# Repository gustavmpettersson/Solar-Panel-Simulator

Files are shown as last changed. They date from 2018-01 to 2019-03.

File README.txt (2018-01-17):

Solar Panel Simulator (SPS) for CubeSat testing

If you use any of this work, we ask that you cite the following individuals and provide a 
link to this repository:
Gustav M. Pettersson
Malte Gruber
Theodor-Adrian Stana
Sven Grahn
Christer Fuglesang
<https://github.com/gustavmpettersson/Solar-Panel-Simulator/>

This project is distributed in the hope that it will be useful, but WITHOUT ANY WARRANTY; 
without even the implied warranty of MERCHANTABILITY or FITNESS FOR A PARTICULAR PURPOSE. 
This should be considered EXPERIMENTAL RESEARCH technology and appropriate care should be 
taken. We will NOT be responsible for ANY related DAMAGES or ISSUES.

This work is Open Source Software and Hardware. See the two included <LICENSE.txt> files 
for details. The software is Copyright 2018 Gustav Pettersson, and released under the GNU 
General Public License. The hardware is Copyright 2018 Gustav Pettersson and Malte Gruber, 
and released under the CERN Open Hardware Licence.

In the root of this repository is a preprint of an article on the SPS submitted to Acta
Astronautica. It contains a lot of (hopefully) useful information on the system.

This system was designed by people working on the MIST and SEAM projects at the KTH Royal 
Institute of Technology.

We invite discussion, collaboration and help with implementing the system. Please contact 
us at <gupet@kth.se> or <gustavpettersson@live.com>.

HERE TO USE THE SPS? START BY READING <Introduction to the SPS>.

HERE TO BUILD THE SPS? HEAD INTO THE HARDWARE FOLDER FOR NECCESSARY FILES. THEN GO TO THE
<Building and Calibrating> FOLDER AND READ <Building Testing and Calibrating the SPS>.

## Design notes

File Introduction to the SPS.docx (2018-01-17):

# Introduction to the SPS

Gustav Pettersson January 2018

# Why the SPS?

Solar panels are used on CubeSats to generate power for the satellite to function. It is vital that the power system on the satellite works as intended to generate the most amount of power possible, and that it has been tested thoroughly. The Solar Panel Simulator (SPS) is used for this purpose. It is a piece of electronics which is designed to act precisely like a solar panel, and in which the exact characteristics of this solar panel can be controlled. It is key to recognise that solar panels do not act like a typical power supply which generates a fixed voltage (and has a maximum amount of current which may be drawn). Instead, a solar panel needs to be actively controlled. The panel presents a characteristic curve of current vs voltage; for each unique voltage applied on the panel by the satellite, a certain current will be delivered. This curve is called the IV curve and is central to understanding the workings and purpose of the SPS. A typical IV curve looks like the solid line below:

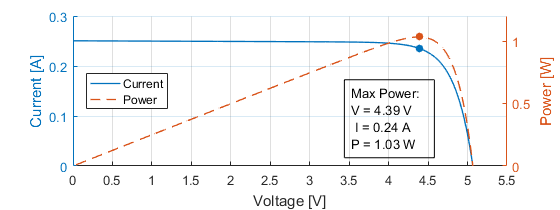
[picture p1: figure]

At a zero voltage, the solar panel produces a certain current (the short-circuit current). As the applied voltage increases, there will be an exponential fall in the produced current, eventually going to zero (the open-circuit voltage). Power (which is what we want!) is the product of voltage and current. Therefore, there is a balance where the voltage is “just right” and the maximum amount of power is produced! This is called the Maximum Power Point (MPP). The power is given in the same plot as the broken line, and the MPP is marked. The satellite power system will try to “chase” this voltage to generate the maximum amount of power. This is called a MPP Tracker (MPPT) and it is implemented in the Solar Array Interface (SAI) of the power system.

# What is the SPS?

The SPS is a device in which an arbitrary IV curve can be programmed to simulate any solar panel on a satellite. It works by measuring the voltage applied by the SAI and then delivering the current programmed into the Lookup Table (LUT) which gives the correct curve. It updates 1000 times per second to ensure the correct current is always given! It looks like this:

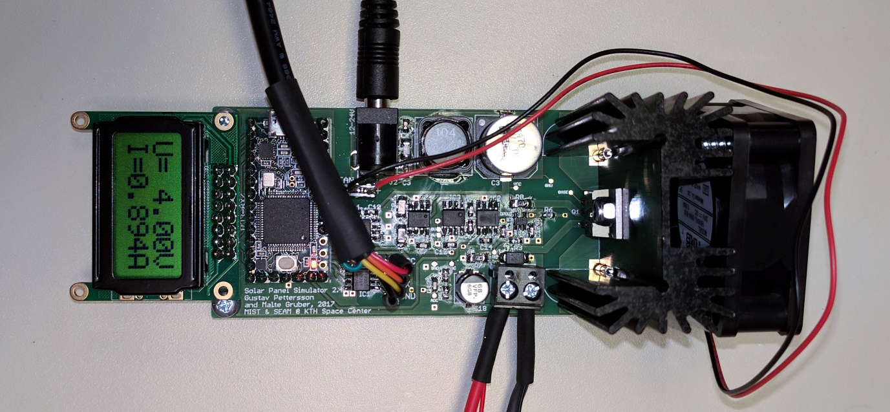
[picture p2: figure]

5 The fan runs directly from the power supply!

6 The fan runs directly from the power supply!

2

4

3

1

There are some key things to point out:

1. The power input. Use a DC power source of 12-24V which is of high quality and isolated from the mains power supply.
2. The power output. This side gets connected to the satellite power system as an input. Please take care that the SPS output is disabled and that the polarity is correct! It is highly recommended to use a connector on this wire (like the one listed in the parts list).
3. The UART connection. This is how the SPS is controlled by the computer. You need to have a UART adapter which provides 3.3-5V connected here, please care for the polarity.
4. The display. This shows what the current output voltage and current is for this SPS. It is very useful to understand how the satellite power system is working!
5. The fan. If you do not use a fan the output is limited to up to 8V 1.1A and a 12V input must be used. If you want to use up to 21V 1.1A, add a 24V fan and use a 24V power supply. If you want to use up to 8V 2.1A use a 12V fan and a 12V power supply. The fan runs directly from the power supply!
6. The Teensy microcontroller. This guy is the brains behind all of it. To program the Teensy use the USB port on it. Never connect power to the SPS and the Teensy USB port at the same time. You may kill your SPS or even your PC!

# How to use the SPS?

Now that we are acquainted, it is time to use the SPS! You will need to know some things:

1. How many inputs will you run?
2. For each input:
  a. What is the maximum voltage and current of the solar panel(s) normally connected?
  b. How will I connect the SPS: Into the harness in place of a panel, or into the power system directly?
3. Do you have an SPS on hand for each input with the correct current and voltage rating?
4. Are you ready to take full responsibility for what happens? The SPS works great for us, but we guarantee nothing. Know what you’re doing, flight hardware is expensive!

If you know these things, go to the instructions for manual control of SPSs in the folder “SPS Manual Control GUI”. Have fun!

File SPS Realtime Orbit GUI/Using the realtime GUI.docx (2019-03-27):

# Using the real-time GUI

Gustav Pettersson January 2018

# Ensure:

You have successfully connected and used all the SPSs on their respective inputs using the manual control GUI. It is imperative that this is done so that everything is connected correctly! If you have not, go to the “SPS Manual Control GUI” folder and follow those instructions.

This guide is only true for the MIST satellite because the simulation data sample in this folder was made for the MIST satellite. This guide is still a useful instruction to understand the purpose and use of the SPS real-time system. We are happy to assist in integrating your simulations for your satellite, just send me an email. Using MIST data on your satellite may destroy it!

# Software setup:

Since you have successfully used the manual GUI and ensured everything is correct, copy exactly the setup from “runManual_SPS_GUI” into “runRealtime_SPS_GUI”. I.e. something like the following:

SPS_HW_IDS = [7 5 6];

SPS_TYPES = {'NO' 'HC' 'HV'};

SPS_LABELS = {'MPPT 1' 'MPPT 2' 'MPPT 3'};

After this, put the desired file to replay in the load statement. E.g. for the sample included:

load('simulationData_MIST_sample.mat');

By default, the software will replay one orbit and then stop. If you wish for it to instead loop back and start from the beginning, add the optional input “true” when starting the GUI:

Stop after one orbit: Realtime_SPS_GUI(SPSs,simulationData);

Loop back to beginning: Realtime_SPS_GUI(SPSs,simulationData,true);

# Hardware setup:

When you have successfully used the manual GUI, do not disconnect the SPSs (to ensure they are not accidentally mixed up) but just close the GUI windows.

# Running:

Run the script. A GUI looking like this should open:

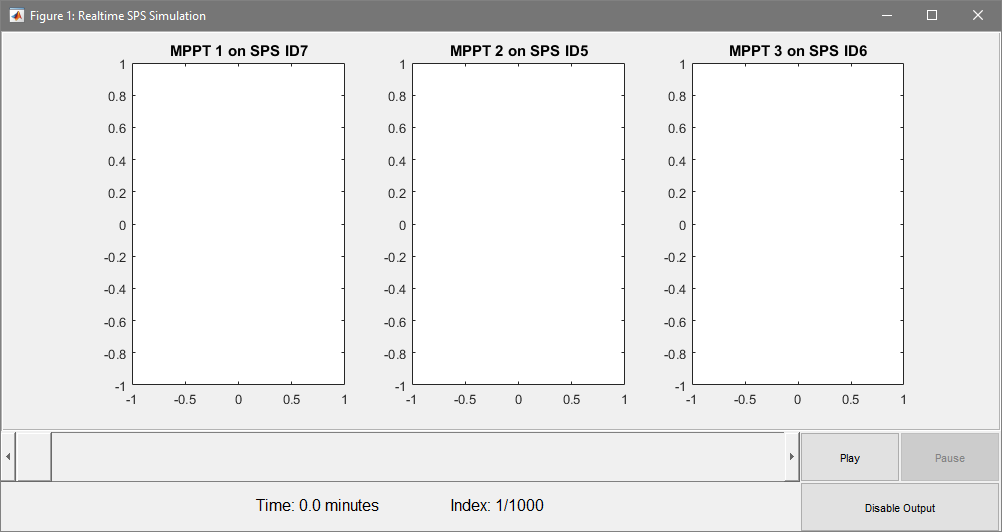
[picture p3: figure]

The top part of this GUI shows one plot window for each SPS. What is shown here is always the curve which is programmed into that SPS. If it is blank like here the SPS is disabled. Along the bottom are the controls. There is a timeline which you may move to a desired starting point; the selected time and index in the simulation are shown. The bottom right holds the controls. Pressing “Play” will start the real-time simulation. In the sample simulation, the satellite comes out of eclipse at around 11 minutes, so this is a good starting point. Press “Play” and you should soon see IV curves appearing. At any time, pressing “Pause” will halt the simulation but keep the current output active. It should look like this:

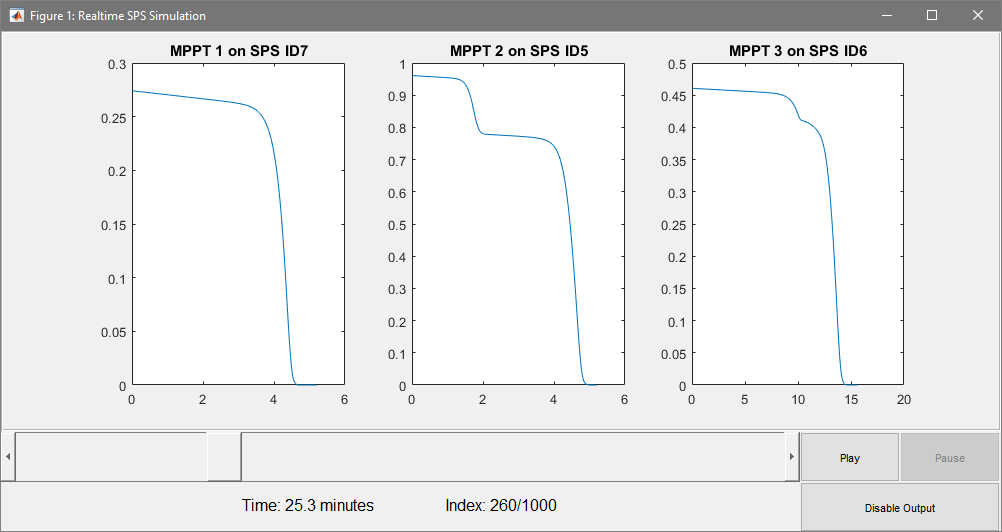
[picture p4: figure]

On the other hand, pressing “Disable Output” will disable the output on the SPSs (and halt the simulation). Now press play and enjoy!

# Shutting down

When finished the program will disable the outputs. If you want to finish early, press “Disable Output”. Read the display on the SPS, it should read (almost) 0A of current. Disconnect it from the satellite power system before unplugging the power to the SPS. Close the Matlab window (If you have unplugged the SPS power, you will get an error message in Matlab, this is expected).

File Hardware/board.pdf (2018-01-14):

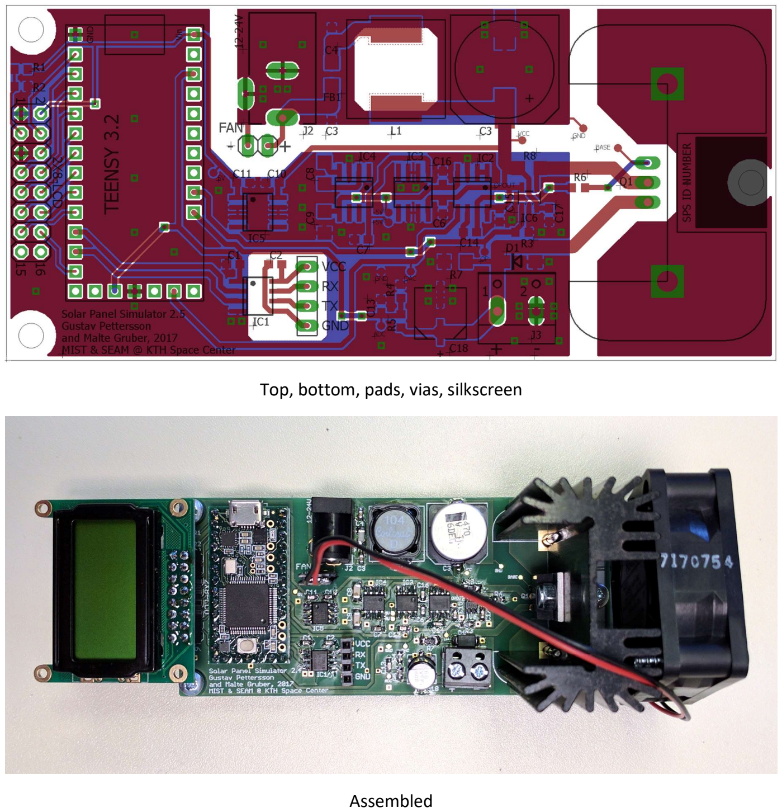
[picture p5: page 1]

Top, bottom, pads, vias, silkscreen

Assembled

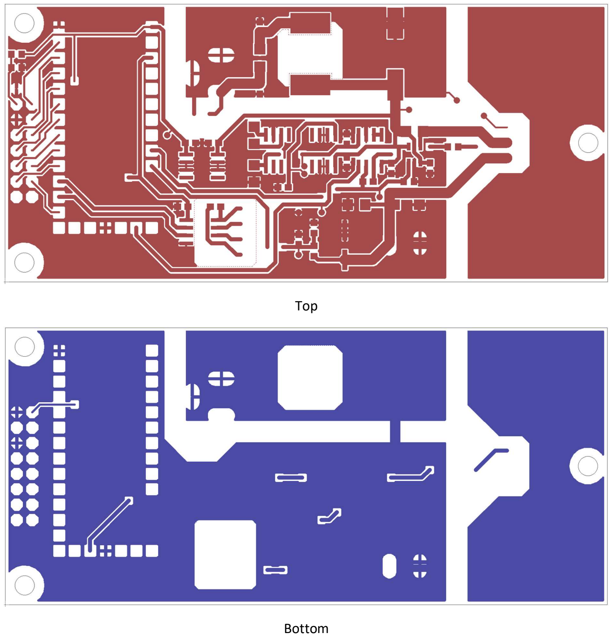
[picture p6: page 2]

Top

Bottom

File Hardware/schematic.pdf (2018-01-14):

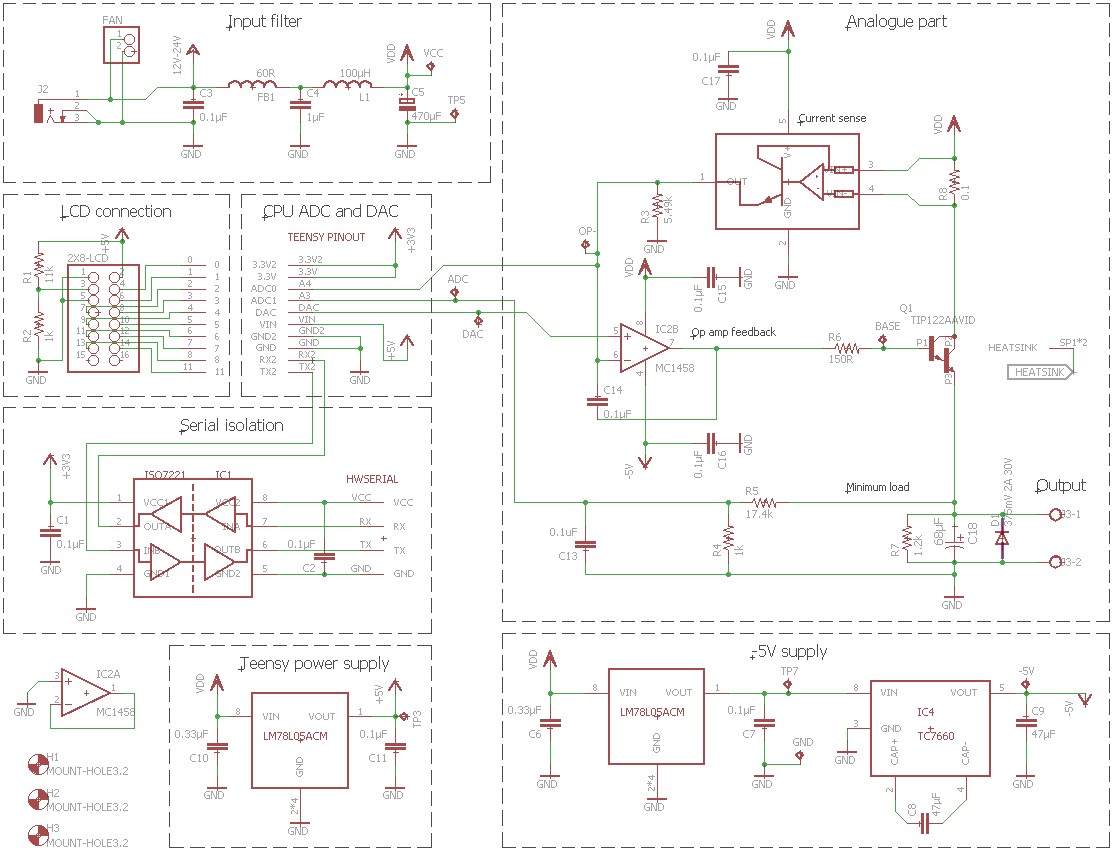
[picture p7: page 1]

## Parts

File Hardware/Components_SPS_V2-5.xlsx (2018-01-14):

Type | Package | Farnell code | Pieces | Note | Components
0.1µF MLCC | 0603 | 2525112 (http://se.farnell.com/tdk/c1608x7r1h104m080aa/kond-mlcc-x7r-0-1-f-50v-0603/dp/2525112) | 11 |  | C1,2,3,7,11,13,14,15,16,17 | Don't mount C12
0.33µF MLCC | 0603 | 2346907 (http://se.farnell.com/tdk/c1608x7r1h334k080ac/cap-mlcc-x7r-330nf-50v-0603/dp/2346907) | 2 |  | C6,10
1µF MLCC | 0603 | 2346909 (http://se.farnell.com/tdk/c1608x7r1v105k080ac/cap-mlcc-x7r-1uf-35v-0603/dp/2346909) | 1 |  | C4
47µF MLCC | 1206 | 2426965 (http://se.farnell.com/murata/grm31cr61a476ke15l/cap-mlcc-x5r-47uf-10v-1206/dp/2426965) | 2 |  | C8,9
68µF Electrolytic | 8mm | 1539500 (http://se.farnell.com/panasonic-electronic-components/eeefpv680xap/cap-alu-elec-68uf-35v-smd/dp/1539500) | 1 |  | C18
470µF Electrolytic | 12.5mm | 2079237 (http://se.farnell.com/panasonic-electronic-components/eeetkv471uaq/cap-alu-elec-470uf-35v-smd/dp/2079237) | 1 |  | C5
0.1R 1% | 1206 | 1107359 (http://se.farnell.com/vishay/wsl1206r1000fea/motst-metallfilm-r1-1-250mw-1206/dp/1107359) | 1 |  | R8
150R 1% | 0603 | 2447255 (http://se.farnell.com/multicomp/mcwr06x1500ftl/res-thick-film-150-ohm-1-0-1w/dp/2447255) | 1 |  | R6
1k 1% | 0603 | 2447272 (http://se.farnell.com/multicomp/mcwr06x1001ftl/motst-tjockfilm-1k-1-0-1w-0603/dp/2447272) | 2 |  | R2,4
1.2k 0.5W | 1206 | 2331866 (http://se.farnell.com/te-connectivity/crgh1206j1k2/motst-tjockfilm-1k2-5-0-5w-1206/dp/2331866) | 1 |  | R7
5.49k 1% | 0603 | 2670841 (http://se.farnell.com/walsin/wr06x5491ftl/motst-tjockfilm-5k49-1-0-1w-0603/dp/2670841) | 1 |  | R3
11k 1% | 0603 | 2447237 (http://se.farnell.com/multicomp/mcwr06x1102ftl/res-thick-film-11kohm-1-0-1w/dp/2447237) | 1 |  | R1
17.4k 1% | 0603 | 2670666 (http://se.farnell.com/walsin/wr06x1742ftl/motst-tjockfilm-17k4-1-0-1w-0603/dp/2670666) | 1 |  | R5
100µH MSS1210-104 | 1210 | 2288307 (http://se.farnell.com/coilcraft/mss1210-104ked/inductor-pwr-100uh-3-4a-10-3-6mhz/dp/2288307) | 1 |  | L1
2A 375mV 30V Schottky | DO-214AC | 1467552 (http://se.farnell.com/stmicroelectronics/stps2l30a/diode-schottky-2a-30v-smd-sma/dp/1467552) | 1 |  | D1
60R Ferrite bead | 1206 | 1651732 (http://se.farnell.com/taiyo-yuden/fbmj3216hm600-t/ferrite-bead-0-01ohm-4a-1206/dp/1651732) | 1 |  | FB1
LM78L05ACM | SO-8 | 2382979 (http://se.farnell.com/texas-instruments/lm78l05aim-nopb/linear-fixed-5v-0-1a-soic-8/dp/2382979) | 2 |  | IC3,5
INA139 | SOT-23 | 1470398 (http://se.farnell.com/texas-instruments/ina139na-250/current-shunt-monitor-40v-5sot23/dp/1470398) | 1 |  | IC6
TC7660 | SO-8 | 1852313 (http://se.farnell.com/microchip/tc7660eoa/ic-charge-pump-dc-dc-conv-8soic/dp/1852313) | 1 |  | IC4
MC1458 | SO-8 | 9589821 (http://se.farnell.com/texas-instruments/mc1458d/op-amp-gen-purpose-dual-smd-1458/dp/9589821) | 1 |  | IC2
ISO7221A | SO-8 | 2764741 (http://se.farnell.com/texas-instruments/iso7221adr/digital-isolator-2-kan-1-5mbps/dp/2764741) | 1 |  | IC1
TIP122 | TO220 | 9557881 (http://se.farnell.com/on-semiconductor/tip122g/darlington-transistor-to-220/dp/9557881) | 1 |  | Q1
8x2 LCD |  | 2674124 (http://se.farnell.com/fordata/fc0802c00-rnnybh-16le/display-alfanumerisk-8x2-inget/dp/2674124) | 1
20p 0.1" male |  | 1593423 (http://se.farnell.com/multicomp/mc34739/connector-header-tht-2-54mm-20way/dp/1593423) | 2
4p 0.1" female |  | 1593460 (http://se.farnell.com/multicomp/2212s-04sg-85/socket-pcb-1-row-4way/dp/1593460) | 1
8x2p 0.1" male |  | 1593445 (http://se.farnell.com/multicomp/2213s-16g/header-2-row-vert-16way/dp/1593445) | 1
5mm terminal block |  | 1716993 (http://se.farnell.com/camdenboss/ctb1202-2bk/terminal-block-wire-to-brd-2pos/dp/1716993) | 1
5.5/2.1mm DC Jack (10 pack) |  | 224959 (http://se.farnell.com/cliff-electronic-components/dc10a/socket-pcb-dc-power-2-1mm-pk10/dp/224959) | 1
AAVID Heatsink |  | 1213474 (http://se.farnell.com/aavid-thermalloy/6399bg/heat-sink-to-220-218-3-3-c-w/dp/1213474) | 1
12V Fan | 40mm | 1012746 (http://se.farnell.com/nmb-technologies/1606kl-04w-b50-l00/fan-40mm-12vdc/dp/1012746) | 1 | for HC
24V Fan | 40mm | 1012748 (http://se.farnell.com/nmb-technologies/1606kl-05w-b50-l00/fan-40mm-24vdc/dp/1012748) | 1 | for HV
12V Power supply |  | 2708288 (http://se.farnell.com/xp-power/vet30us120c2-ja/adapter-ac-dc-12v-2-5a/dp/2708288) | 1 | for HC
24V Power supply |  | 2708291 (http://se.farnell.com/xp-power/vet30us240c2-ja/adapter-ac-dc-24v-1-25a/dp/2708291) | 1 | for HV
Mains cable |  | 1283799 (http://se.farnell.com/pro-elec/sh10167r/power-cord-euro-to-fig-8-2m/dp/1283799) | 1
USB cable |  | 2464950 (http://se.farnell.com/roline/11-02-8760/kabel-usb-2-0-a-micro-b-kont-1m/dp/2464950) | 1
Teensy 3.2 board |  | Mouser/PJRC | 1
M3 6mm (100 pack) |  | 1419986 (http://se.farnell.com/duratool/m36-prstmcz100/screw-steel-bzp-6mm-m3-pk100/dp/1419986) | 4
M3 nut (100 pack) |  | 1420431 (http://se.farnell.com/duratool/m3-n5st-z100/nut-locking-steel-bzp-m3-pk100/dp/1420431) | 1
M3 20mm self tap (100 pack) |  | 2474974 (http://se.farnell.com/tr-fastenings/3-020krst30tc1d/skruv-pozi-g-ngbildande-m3-x-20mm/dp/2474974) | 2
M3 8mm standoff |  | 1466741 (http://se.farnell.com/ettinger/05-03-083/spacer-m3x8-ni/dp/1466741) | 3

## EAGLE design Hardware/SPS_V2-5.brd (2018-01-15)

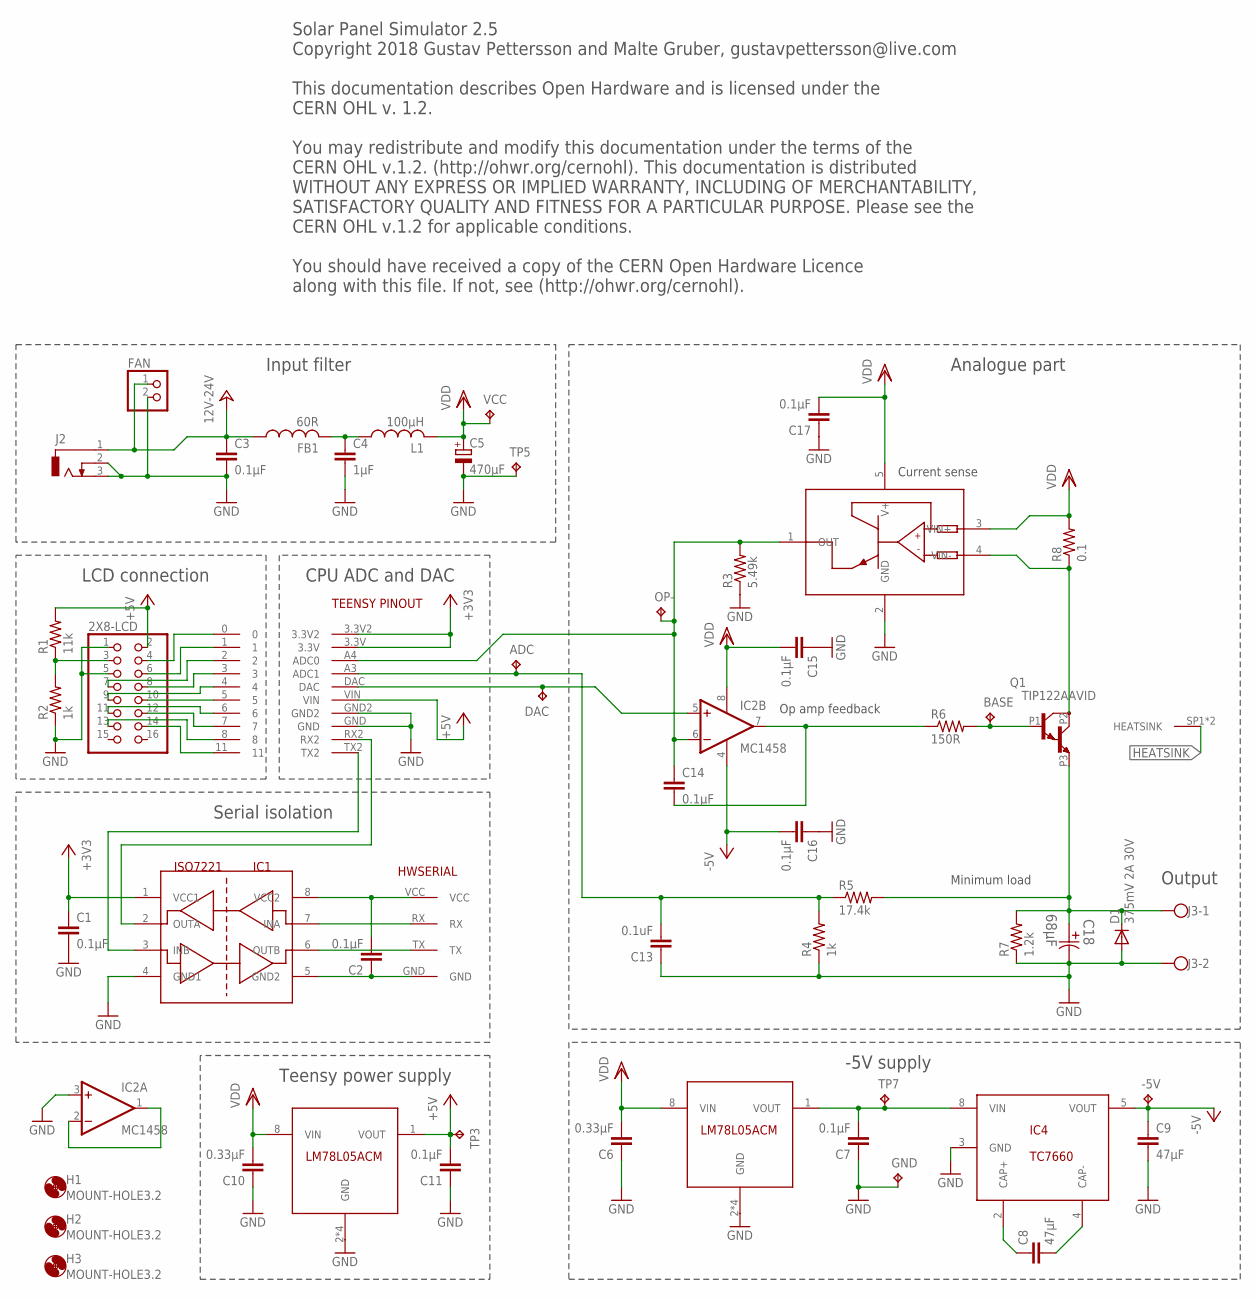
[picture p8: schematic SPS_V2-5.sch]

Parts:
2X8-LCD: PINHD-2X8; 2X08
-5V: TPTP10R; TP10R
ADC: TPTP10R; TP10R
BASE: TPTP10R; TP10R
C1, C2, C3, C7, C11, C14, C15, C16, C17: 0.1µF; C0603
C4: 1µF; C0603
C5: 470µF; 12.5MMSMD
C6, C10: 0.33µF; C0603
C8, C9: 47µF; C1206
C13: 0.1uF; C0603
C18: 68µF; CAPAE660X800N
D1: 375mV 2A 30V; DO214AC
DAC: TPTP10R; TP10R
DB1: TEENSY3.2
FAN: PINHD-1X2; 1X02
FB1: 60R; R1206
GND: TPTP10R; TP10R
H1, H2, H3: MOUNT-HOLE3.2; 3,2
IC1: ISO7221; SO8
IC2: MC1458; SO08
IC3, IC5: LM78L05ACM; SO8
IC4: TC7660; SO8
IC6: INA139; SOT23-5L
J1: HWSERIAL
J2: DCJ0303
J3: W237-102
L1: 100µH; 1210INDUCTOR
OP-: TPTP10R; TP10R
Q1: TIP122AAVID; OP-220-AAVID
R1: 11k; R0603
R2, R4: 1k; R0603
R3: 5.49k; R0603
R5: 17.4k; R0603
R6: 150R; R0603
R7: 1.2k; R1206
R8: 0.1; R1206
TP3, TP5, TP7: TPTP10R; TP10R
VCC: TPTP10R; TP10R

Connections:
+3V3: C1.1, DB1.3.3V, DB1.3.3V2, IC1.1 (VCC1)
+5V: 2X8-LCD.2, C11.2, DB1.VIN, IC5.1 (VOUT), R1.2, TP3.TP
+24V: C3.1, FAN.1, FB1.1, J2.1
-5V: -5V.TP, C9.1, C16.2, IC2.4 (V-), IC4.5 (VOUT)
GND: 2X8-LCD.1, 2X8-LCD.5, C1.2, C3.2, C4.2, C5.P$1 (-), C6.1, C7.1, C9.2, C10.1, C11.1, C13.1, C15.1, C16.1, C17.1, C18.2, D1.A, DB1.GND, DB1.GND2, FAN.2, GND.TP, IC1.4 (GND1), IC2.3 (+IN), IC3.2 (GND), IC3.3 (GND), IC3.6 (GND), IC3.7 (GND), IC4.3 (GND), IC5.2 (GND), IC5.3 (GND), IC5.6 (GND), IC5.7 (GND), IC6.2 (GND), J2.2, J2.3, J3.2, R2.1, R3.1, R4.1, R7.1, TP5.TP
HEATSINK: Q1.SP1 (HEATSINK), Q1.SP2 (HEATSINK)
unnamed: C14.2, IC2.7 (OUT), R6.1
unnamed: BASE.TP, Q1.P1 (B), R6.2
unnamed: C4.1, FB1.2, L1.P$1 (1)
unnamed: C14.1, DB1.A4 (ADC0), IC2.6 (-IN), IC6.1 (OUT), OP-.TP, R3.2
unnamed: C2.2, IC1.8 (VCC2), J1.VCC
unnamed: ADC.TP, C13.2, DB1.A3 (ADC1), R4.2, R5.1
unnamed: IC1.7 (INA), J1.RX
unnamed: DAC.TP, DB1.DAC, IC2.5 (+IN)
unnamed: 2X8-LCD.4, DB1.0
unnamed: IC6.4 (VIN-), Q1.P2 (C), R8.1
unnamed: IC1.6 (OUTB), J1.TX
unnamed: C8.2, IC4.4 (CAP-)
unnamed: C8.1, IC4.2 (CAP+)
unnamed: DB1.RX2, IC1.2 (OUTA)
unnamed: DB1.TX2, IC1.3 (INB)
unnamed: C2.1, IC1.5 (GND2), J1.GND
unnamed: C7.2, IC3.1 (VOUT), IC4.8 (VIN), TP7.TP
unnamed: 2X8-LCD.6, DB1.1
unnamed: 2X8-LCD.7, DB1.2
unnamed: 2X8-LCD.8, DB1.3
unnamed: 2X8-LCD.9, DB1.4
unnamed: 2X8-LCD.10, DB1.5
unnamed: 2X8-LCD.11, DB1.6
unnamed: 2X8-LCD.12, DB1.7
unnamed: 2X8-LCD.13, DB1.8
unnamed: 2X8-LCD.14, DB1.11
unnamed: 2X8-LCD.3, R1.1, R2.2
unnamed: IC2.1 (OUT), IC2.2 (-IN)
unnamed: C18.1, D1.C, J3.1, Q1.P3 (E), R5.2, R7.2
VDD: C5.P$2 (+), C6.2, C10.2, C15.2, C17.2, IC2.8 (V+), IC3.8 (VIN), IC5.8 (VIN), IC6.3 (VIN+), IC6.5 (V+), L1.P$2 (2), R8.2, VCC.TP

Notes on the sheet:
Teensy power supply
Serial isolation
-5V supply
Analogue part
Input filter
Current sense
Op amp feedback
Minimum load
Output
CPU ADC and DAC
LCD connection
Solar Panel Simulator 2.5 Copyright 2018 Gustav Pettersson and Malte Gruber, gustavpettersson@live.com This documentation describes Open Hardware and is licensed under the CERN OHL v. 1.2. You may redistribute and modify this documentation under the terms of the CERN OHL v.1.2. (http://ohwr.org/cer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

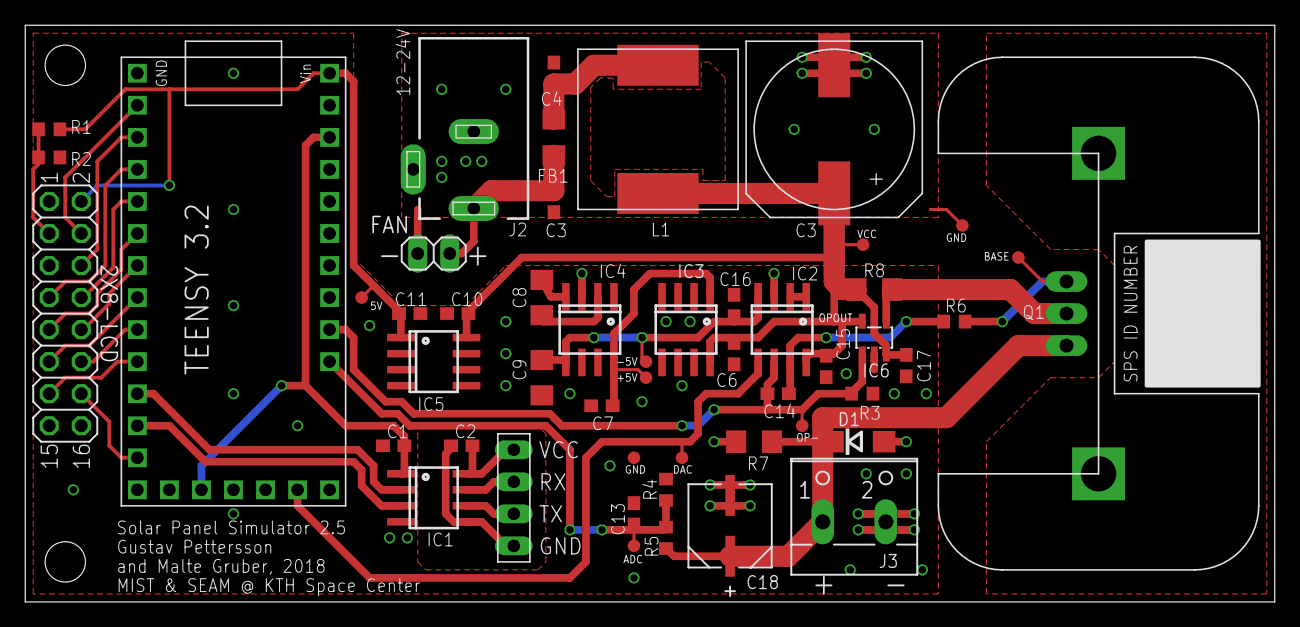
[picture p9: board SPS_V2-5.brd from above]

Board: 2 copper layers, 99.1 x 45.7 mm, 54 parts (0 on the bottom side), 36 nets.

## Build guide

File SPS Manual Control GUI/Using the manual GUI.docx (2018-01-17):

# Using the manual GUI

Gustav Pettersson January 2018

# Ensure:

You have read and understood the “Introduction to the SPS” document and that you have your SPSs ready for use. First, we need to set up the software.

# Software setup:

Open “runManual_SPS_GUI” in Matlab. There are three fields that must be filled in correctly. For each SPS you will use you need to know the following:

1. What is the unique hardware ID of this SPS?
2. What power input and fan is this SPS using? Only these answers are acceptable:
  a. NO: No fan and 12V input. Limited to 8V 1.1A.
  b. HC: 12V fan and 12V input. Limited to 8V 2.1A.
  c. HV: 24V fan and 24V input. Limited to 21V 1.1A.
3. What input on the satellite will this SPS be connected to?

Note that the SPS measures voltage and provides current. It is safe to use a higher voltage rating on the SPS than the input on the satellite in normal operation. BUT if there is a problem the SPS may short and send the voltage through! Use a fuse and Zener diode to build a simple and reliable overvoltage and overcurrent protection (see e.g. here (http://www.learningaboutelectronics.com/Articles/Overvoltage-protection-circuit.php)).

List the hardware IDs you are using:

SPS_HW_IDS = [7 5 6];

Then, keeping order intact, list the types:

SPS_TYPES = {'NO' 'HC' 'HV'};

Then, keeping order intact, list the input you will simulate. List either ‘MPPT x’ or ‘PANEL x’ where x is replaced with a number.

SPS_LABELS = {'MPPT 1' 'MPPT 2' 'MPPT 3'};

Make sure the SPSs are not connected to the satellite and run the script. All being well, you should get windows looking like these opening: (one for each SPS)

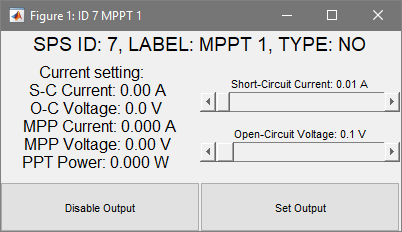
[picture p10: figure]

On the top row, the parameters for this SPS are shown. Ensure that the hardware ID, label, and type match what you expect! Now click “Disable Ouput” and see that the LED on the Teensy becomes brighter momentarily (this is when the Teensy is receiving data), so that you also have the correct SPS connected to the expected window. Repeat this for all SPSs. If all is well you may proceed to connecting the hardware to you satellite.

# Hardware Setup

Start your satellite power system and stream the housekeeping data to a computer to keep an eye on its status. With the SPS outputs all disabled, connect them to the satellite power system in the desired ports. Always be ready to unplug the power if anything seems strange! Now, for one SPS at a time, set the short-circuit current and open-circuit voltage to something reasonable (e.g. 0.1A 6V) and press “Set Output”. The GUI should look something like this:

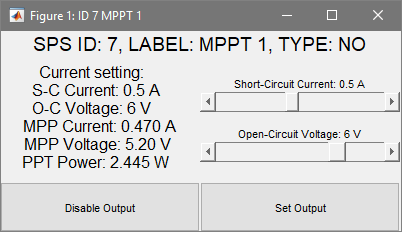
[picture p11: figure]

On the left-hand side, the current settings are listed. Look in the housekeeping data to see that the correct input (in this case MPPT 1) has been powered. Compare the input voltage and current on the SPS display and the housekeeping data, they should match! Disable this output and then repeat for all other connected SPSs.

Congratulations! Your satellite is now powered by the SPS and you can begin testing. The first thing to note is the MPP current and voltage. The housekeeping data should report something similar, otherwise the MPPT is not doing its job! Now play around with the voltage and current that you set to the power system on the various SPSs, and click “Set Ouput” to send your settings.

# Shutting down

When you are finished, click “Disable Output” on each SPS. Read the display on the SPS, it should read (almost) 0A of current. Disconnect it from the satellite power system before unplugging the power to the SPS. Close the Matlab windows (If you have unplugged the SPS power, you will get an error message in Matlab, this is expected).

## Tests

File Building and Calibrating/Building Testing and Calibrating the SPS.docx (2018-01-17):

# Building, Testing, and Calibrating the SPS

Gustav Pettersson January 2018

# Building

1. The required components to build the SPS PCB are given in the “Components_SPS_V2-5” excel file and the PCB design plans are in the “SPS_V2-5” Eagle files.
2. Install the standoffs.
3. The components are surface mount, but can be hand soldered without issue. First install all small components and packages, then the large ones.
4. The display and teensy are both mounted by placing .1” headers between the board and component (using only male headers and soldering directly is fine).
5. The TIP-122 should be first mounted to the heatsink and then placed as one component. Solder down the heatsink legs first, then the TIP-122.
6. Attach fan, noting that the fan is powered directly from the input voltage and must be selected accordingly. If less than half of maximum current is used, the fan may be omitted.

# Testing

1. Connect a micro USB cable to the Teensy, select the Teensy COM port and board in the Arduino IDE (follow instructions on www.pjrc.com/teensy/teensyduino.html for details)
2. Upload the code “SPSTeensy” to the board through the Arduino IDE.
3. The display should come on, displaying the current and voltage (about 2.5V, 0A) at output.
4. Connect the TTL-232RG UART-USB adapter between the PC and SPS. Select the newly appearing COM port in the Arduino IDE.
5. Test that communication (over UART adapter, 115200 baud) works by sending “W” over the serial port and receiving “SPS”. (Use Tools > Serial Monitor)
6. Set a unique board ID by sending “S#” (where # is 1-255), retrieve by sending “I”. (This is stored permanently in the EEPROM.)
7. Mark the SPS with the board ID and input voltage.
8. Disconnect the Teensy USB cable.
9. Connect a 12V lab supply with a 100mA current limit. The SPS should turn on and draw around 50 mA. (Fan disconnected.)
10. Connect the SPS to a DC load set to 5V. Increase current limit on lab supply to 500 mA. Open the programme “SendDACvalue”, input the COM port used before (when setting the ID) and run. The programme should say “Connected to device with hardware ID #”. Connect fan.
11. (Recommended: Connect oscilloscope to transistor base to check for oscillations during the following steps.)
12. Enter 500 and send. The current should read about 260mA. Vary voltage 0-10V.
13. Increase current limit to 1A, send 1000. Should give around 530mA. Vary voltage 0-10V.
14. Increase current limit to 2A, send 2000. Should give around 1060mA. Vary voltage 0-10V.
15. Send 3000. Should give around 1600mA. Vary voltage 0-10V.
16. Increase current limit to 2.2A, send 3800. Should give around 2020mA. Vary voltage 0-10V.
17. Send 0 to disable the SPS. The testing is complete. (Use Ctrl-C to exit the programme.)

# Calibrating

## Voltage

1. Connect a 24V fan. Use a lab supply with 24V input and 500mA current limit.
2. Connect to DC load, set the load to constant voltage, 5V.
3. Use “SendDACvalue” to set the DAC to 500 (around 260mA).
4. Ctrl-C out, run “ReadADCvalues”, the terminal should start printing the voltage and current shown on the display, as well as “DAC: 500” and “ADC: xxx”.
5. Use the DC load to set the following voltages one by one: .1 .25 .5 1 2 3 4 5 6 7 8 9 10 11 12 13 14 15 16 17 18 19 20 21. Write down the ADC value printed in Matlab for each.
6. Use Ctrl-C to exit the script and then run “ReadADCvaluesSTOP”.
7. Run “SendDACvalue” and send 0 to disable the SPS.

## Current

1. Connect a 12V fan. Use a lab supply with 12V input and 2.5A current limit.
2. Connect to DC load, set the load to constant voltage, 5V.
3. Open “SendDACvalue” and set the DAC to the following values one by one: 10 25 50 100 200 400 600 800 1000 1200 1400 1600 1800 2000 2200 2400 2600 2800 3000 3200 3400 3600 3800 4000. Write down the measured current on the DC load for each.
4. Send 0 to disable the SPS.

## Calculating

1. Input the values from the voltage and current calibration in the script “CalculateCalibrationPolynomials”. Run the script.
2. Check that the plots show straight lines and no outliers.
3. A “Calibration string” should be generated similar to: “1876.1 -3.0523 0.0053984 0.026077”
4. Open the Matlab variable “SPSCalibrationData” and add a new line. The first entry is the hardware id # programmed into the SPS and the following four is the calibration string:
  a. load(‘SPSCalibrationData.mat’)
  b. SPSCalibrationData = [SPSCalibrationData; # 1876.1 -3.0523 0.0053984 0.026077]
  c. Check that the new line was added correctly.
  d. save(‘SPSCalibrationData.mat’)

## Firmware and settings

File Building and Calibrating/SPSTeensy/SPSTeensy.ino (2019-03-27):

// Copyright 2018 Gustav Pettersson, gustavpettersson@live.com
// 
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


#include <ADC.h>            //https://github.com/pedvide/ADC
#include <EEPROM.h>         //https://www.arduino.cc/en/Reference/EEPROM
#include <LiquidCrystal.h>  //https://www.arduino.cc/en/Reference/LiquidCrystal

int DeviceID = EEPROM.read(0); //Keep unique ID in first index of EEPROM

//Lookup tables used to set the IV curve
uint16_t LookupA[4096] = {0};
uint16_t LookupB[4096] = {0};

//Start with active pointer on LookupA
uint16_t* activeLookup = &LookupA[0];
uint16_t* inactiveLookup = &LookupB[0];

uint16_t DACvalue = 0;
uint16_t ADCvoltvalue = 0;
uint16_t ADCcurrvalue = 0;

uint16_t newValue = 0;
bool byteValid = true;
bool arrayValid = true;

bool LEDActive = false;
bool printValues = false;
elapsedMillis sincePrint;

const int ADCvolt = A3;
const int ADCcurr = A4;
ADC *adc = new ADC();

const int DACPin = A14;
IntervalTimer samplingTimer;
IntervalTimer displayTimer;

LiquidCrystal lcd(0, 1, 2, 3, 4, 5, 6, 7, 8, 11);

void setup() {
  Serial2.begin(115200);
  Serial2.setTimeout(10); //String read timeout 10 ms
  pinMode(LED_BUILTIN,OUTPUT);
  analogWriteResolution(12);
  analogReference(INTERNAL); //INTERNAL is 1.195V 0.5%. EXTERNAL is 3.3V.
  pinMode(ADCvolt,INPUT);
  pinMode(ADCcurr,INPUT);
  
  //adc->analogRead(ADCvolt,ADC_1);
  //adc->analogRead(ADCcurr,ADC_0);
  
  adc->setResolution(12,ADC_0);
  adc->setAveraging(16,ADC_0);
  adc->setSamplingSpeed(ADC_SAMPLING_SPEED::LOW_SPEED,ADC_0);
  adc->setReference(ADC_REFERENCE::REF_1V2,ADC_0);
  adc->setResolution(12,ADC_1);
  adc->setAveraging(16,ADC_1);
  adc->setSamplingSpeed(ADC_SAMPLING_SPEED::LOW_SPEED,ADC_1);
  adc->setReference(ADC_REFERENCE::REF_1V2,ADC_1);
  
  pinMode(DACPin,OUTPUT);
  analogWrite(DACPin, 0);

  lcd.begin(8,2);
  lcd.write("U= 0.00V");
  lcd.setCursor(0,1);
  lcd.write("I=0.000A");

  samplingTimer.priority(128);
  samplingTimer.begin(update, 1000); //Update every 1 ms
  displayTimer.priority(255);
  displayTimer.begin(writeLCD, 500000); //Update every 500 ms
}

void writeLCD() {
  char voltage[5];
  sprintf(voltage, "%*.2f", 5, ADCvoltvalue/186.2);
  char current[5];
  sprintf(current, "%*.3f", 5, ADCcurrvalue/1881.3);
  lcd.setCursor(2,0);
  lcd.write(voltage);
  lcd.setCursor(2,1);
  lcd.write(current);
}

void update() {
  ADCvoltvalue = adc->analogRead(ADCvolt,ADC_1);
  ADCcurrvalue = adc->analogRead(ADCcurr,ADC_0);
  //Check that first four bits are zero (i.e. we have 12 bit number in the 16 bit uint)
  if ( !(ADCvoltvalue & 0xF000) ) { 
    DACvalue = *(activeLookup+ADCvoltvalue);
    analogWrite(DACPin, DACvalue);
    if (printValues && sincePrint>100) {
      sincePrint = 0;
      char voltage[5];
      sprintf(voltage, "%*.2f", 5, ADCvoltvalue/186.2);
      char current[5];
      sprintf(current, "%*.3f", 5, ADCcurrvalue/1881.3);
      Serial2.print("ADC volt: ");
      Serial2.print(voltage);
      Serial2.print(" ADC curr: ");
      Serial2.print(current);
      Serial2.print(" DAC: ");
      Serial2.print(DACvalue);
      Serial2.print(" ADC: ");
      Serial2.println(ADCvoltvalue);
    }
  }
}

void loop() {
  if (Serial2.available() > 0) {
    String task = Serial2.readString();
    if (task.substring(0,1).equals("W")) {        //Who
      Serial2.print("SPS\n");
    } else if (task.substring(0,1).equals("V")) { //Verison
      Serial2.print("1\n");
    } else if (task.substring(0,1).equals("P")) { //Print values
      printValues = true;
    } else if (task.substring(0,1).equals("H")) { //Stop printing
      printValues = false;
    } else if (task.substring(0,1).equals("T")) { //Dump tables
      for (int i=0; i<4096; i+=256) {
        Serial2.println(*(activeLookup+i));
        Serial2.println(*(inactiveLookup+i));
      }
    } else if (task.substring(0,1).equals("I")) { //Get ID
      Serial2.print(DeviceID);
      Serial2.print("\n");
    } else if (task.substring(0,1).equals("S")) { //Set ID
      int setID = task.substring(1).toInt();
      if (setID > 0 && setID < 255) {
        EEPROM.write(0,setID);
        DeviceID = setID;
        Serial2.println("ID set!");
      } else {
        Serial2.println("Forbidden number!");
      }
    } else if (task.substring(0,1).equals("D")) { //Set lookup table
      // This is where the fun begins, we are getting data!
      LEDActive = true;
      digitalWrite(LED_BUILTIN,HIGH);
      Serial2.print("OK\n"); //Acknowledge we are ready for the transfer
      arrayValid = true;
      //Wait for the buffer to fill with the data
      unsigned long startTime = millis();
      int i = 0;
      while ( (millis()-startTime)<5000 && i<4096 ) {     
        if (Serial2.available()>1) { //If there are at least two bytes in buffer, read in
          newValue = 0;
          byteValid = true;
          //Read MSBs and insert
          uint8_t msb = Serial2.read();
          if ( !(msb>>6 ^ B10) ) { //Check identifier
            msb = msb & B00111111; //Remove identifier
          } else {byteValid = false;}
          //Read LSBs and insert
          uint8_t lsb = Serial2.read();
          if ( !(lsb>>6 ^ B01) ) { //Check identifier
            lsb = lsb & B00111111; //Remove identifier
          } else {byteValid = false;}
          if (byteValid) {
            *(inactiveLookup + i) = msb<<6 | lsb; //Put new value in inactive array
            i = i+1; //Increment pointer
          } else {
            Serial2.println("Read Error, value not valid!");
            arrayValid = false;
            break;
          }
        }
      }
      
      if ((i==4096) && !Serial2.available()){ //If we read all values and the buffer is now empty
        arrayValid = true;
      } else {
        Serial2.println("Read Error, array not valid!"); //Something failed
      }

      //Switch the active/inactive pointers if all went as planned
      if (arrayValid) {
        noInterrupts();
        uint16_t* temp = activeLookup;
        activeLookup = inactiveLookup;
        inactiveLookup = temp;
        interrupts();
        Serial2.print("F\n"); //Acknowledge we are done with the transfer
      }
      else {
        Serial2.println("Read Error at End"); //Something failed
      }
    }
  } else {
    //Keep LED at 50% duty cycle with unused CPU time
    if (LEDActive) {
      LEDActive = false;
      digitalWrite(LED_BUILTIN,LOW);
    } else {
      LEDActive = true;
      digitalWrite(LED_BUILTIN,HIGH);
    }
  }
}

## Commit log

2018-01-15 minor updates
    [SPS_V2-5.brd]
2019-01-22 SPSTeensy updated
    The SPSTeensy.ino file was updated to no longer rely on a large serial input buffer
    [SPSTeensy.ino]

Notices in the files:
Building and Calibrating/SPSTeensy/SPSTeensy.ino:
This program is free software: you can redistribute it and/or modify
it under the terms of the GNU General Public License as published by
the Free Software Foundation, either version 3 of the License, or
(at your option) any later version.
